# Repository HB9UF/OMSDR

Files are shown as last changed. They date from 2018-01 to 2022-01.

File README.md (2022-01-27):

# OMSDR: An SMD soldering practice kit for hams

## Introduction

OMSDR is a simple HF SDR receiver frontend inspired by the [SoftRock Lite II](http://fivedash.com/index.php?main_page=product_info&products_id=5). It is designed as SMD soldering practice kit to demonstrate the power of SMD technology, meant as an entry point for amateur radio hobbyists who are afraid of SMD. To allow for an easy entrance, most components are fairly large -- much larger than what you usually use in SMD designs. Our position is that SMD soldering is not hard if you know the proper techniques, and that a kit such as this one makes it easy to acquire these techniques. Note that this is not a particular good radio, and if you are not in for the aforementioned SMD aspects, you are probably better off with a different kit. If one of the following is of interest to you, though, then this may be for you:

1. Easy to assemble SMD kit with large parts and large footprints designed for entry level SMD hand soldering.
2. This kit makes for a good learning experience if you are interested in the Tayloe mixer circuitry that is the basis for these types of SDR frontends. The relevant signals are easy to probe, allowing for a deeper understanding of the circuit.

The circuit stored in this repository is designed for the 40 meter amateur radio band, although it is relatively easy (and hopefully instructional) to alter the design for operation on another band. If you do so, we would very much like to hear from you.

## Schematic
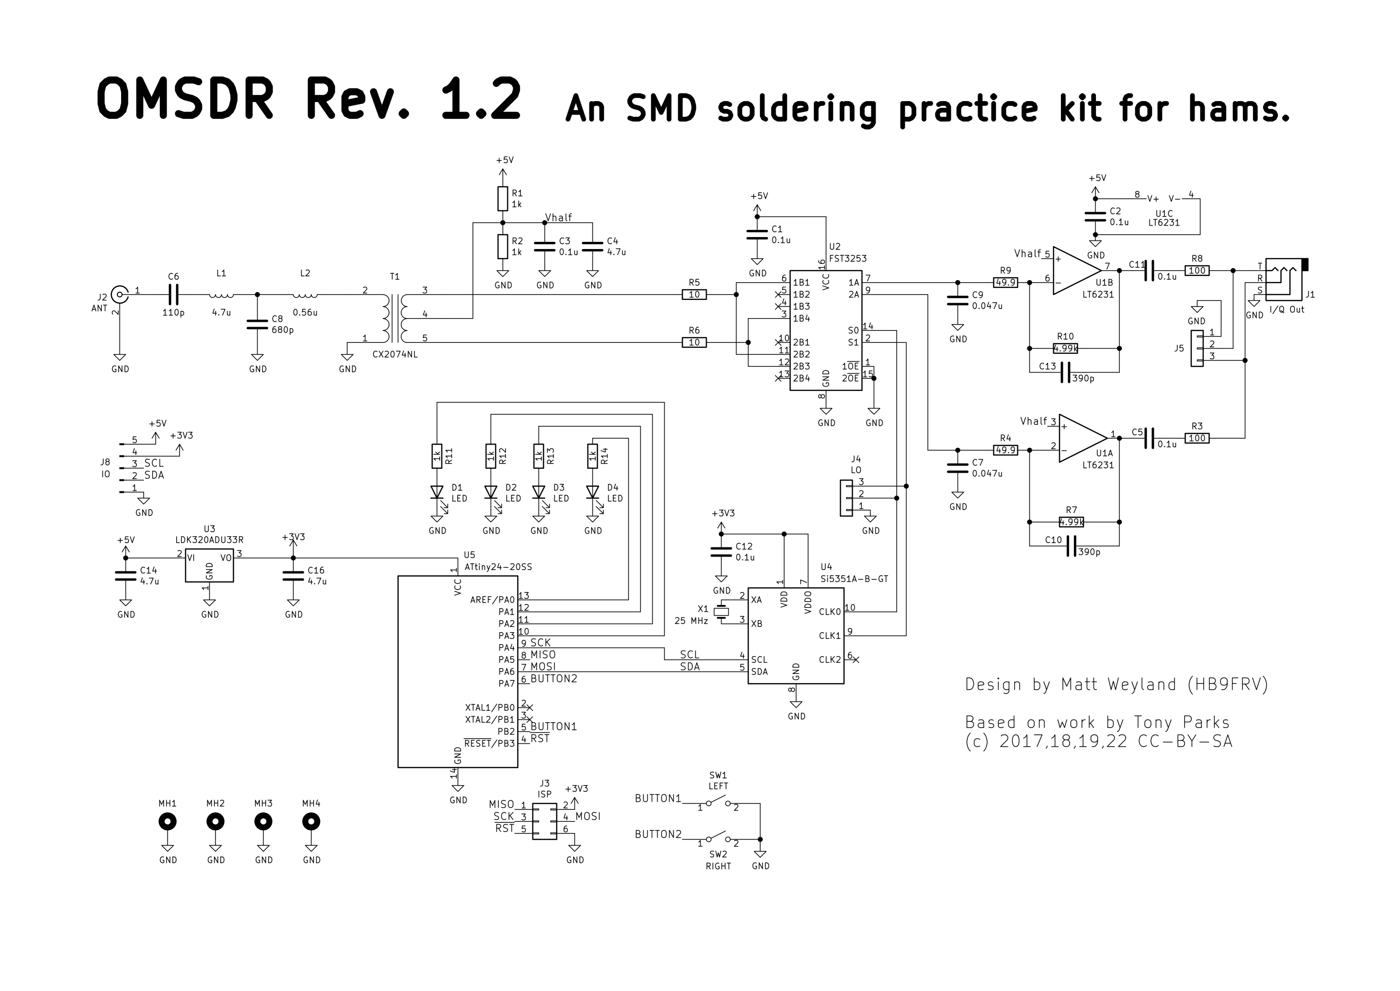
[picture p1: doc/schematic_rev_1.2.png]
Schematic rev 1.2


## Key differences to Soft Rock Lite II
This is not an exact copy of the design by Tony Parks. Instead, we opted for the following key differences:

- You don't have to wind any magnetic components. We use SMD inductors in the frontend filter (which we redesigned somewhat) and we use an SMD transformer (CX2074NL) for the balun.

- The original design employs a common-collector Colpitts oscillator to generate the reference for the local oscillator. We replaced that with a Silabs si5351 clock generator for versatility.

- The reference from the aforementioned Colpitts oscillation is fed into a dual D-Flip-Flop to generate a quadrature clock in the original design, yielding two square waves at a quarter of the reference frequency with a phase difference of 90°. We generate the quadrature clock directly with the si5351 clock generator.

- We use a microcontroller to program the clock generator. We chose an Attiny24 for this but this can be easily swapped out for something else. The clock generator is programmed via I2C and this bus is accessible through a pin header. Thus you could choose not to populate the microcontroller and use, e.g., a Raspberry Pi instead. Using a programmable clock generator allows us to change the center frequency of the SDR within the band, thus covering the whole 40 meter band. The original design has a fixed oscillator at approx. 7.056 MHz, thus even if you use a sampling rate of 96 kHz, it only covers the lower half of the band.

- a 3.5 mm audio jack can be plugged directly into the OMSDR board to connect to the sound card.

- Our design is fully open source.

## Bill of Materials

A BOM csv file is available [here](https://raw.githubusercontent.com/HB9UF/OMSDR/master/doc/BOM_rev1.2.csv) -- note that there is an aggregated table at the bottom. The `BOM` column follows the `bomtool` format, which is a retired tool by Alexis Lockwood. Essentially, digikey order numbers are prefixed with `DIST DIGIKEY` and for passives, we specify parts requirements that used to be processed by `bomtool` to pick the cheapest available part from digikey. Let us know if you are looking for a BOM or have compiled one yourself -- we have to transition to a new BOM format and that would be a good motivation to do so. Please also note that we did not include the pin headers because we believe that most builders will have those in bulk, and also because it pays off to buy them in bulk. For assembly, we have an interactive BOM [here](https://htmlpreview.github.io/?https://github.com/HB9UF/OMSDR/master/doc/ibom_rev1.2.html).

## Firmware

Firmware is available in the `firmware` subdirectory. To compile, run `make` and then flash the microcontroller using your favorite method, for example:

```
avrdude -v -pt44 -cstk500v2 -Pusb -Uflash:w:40m.hex:i
```

On a Debian system or a distribution based on Debian, you will need the packages `make`, `gcc-avr`, `avr-libc`, `binutils-avr` and `avrdude`  for this to work.

On power-up, the firmware cycles through the LEDs and initialized the local oscillator at 7.020 MHz. With a sound card sampling at 48 kHz, you will have access to the spectrum between 6.996 MHz and 7.044 MHz, i.e., the low end of the 40 meter amateur radio band. In this mode, the leftmost LED will be on and the remaining LEDs will be off: `[x][ ][ ][ ]`. Pushing the bottom button moves the center frequency to 7.060 MHz, covering the spectrum from 7.036 MHz to 7.084 MHz. The corresponding LED indicator reads `[x][x][ ][ ]`. In this manner, you can tune through different portions of the band according to the following frequency plan (center frequency indicated in parentheses):

```
       [x][ ][ ][ ]       [x][x][ ][ ]        [ ][x][x][ ]        [ ][ ][x][x]       [ ][ ][ ][x]
6.996  --(7.020)--  7.044
7.000  --(7.020)--  7.040
                    7.036  --(7.060)--  7.084
                    7.040  --(7.060)--  7.080
                                        7.076  --(7.100)--  7.124
                                        7.080  --(7.100)--  7.120
                                                            7.116  --(7.140)-- 7.164
                                                            7.120  --(7.140)-- 7.160
                                                                               7.156  --(7.180)-- 7.204
                                                                               7.160  --(7.180)-- 7.200
```

## Software and License
This board files were designed with KiCad 6. They are licensed under the CC-BY-SA license. More information on this license can be found [here](https://creativecommons.org/licenses/by-sa/4.0/). The software is licensed under the [GNU GENERAL PUBLIC LICENSE Version 3](https://www.gnu.org/licenses/gpl-3.0.en.html)

## References

The paper "Ultra Low Noise, High Performance, Zero IF Quadrature Product Detector and Preamplifier" by Dan Tayloe is a nice introduction to the principles of Tayloe quadrature product detectors. We are not sure where it was published originally, but it is available [here](http://www.norcalqrp.org/files/Tayloe_mixer_x3a.pdf). For a more intricate introduction, including software aspects, we refer to the article series "A Software-Defined Radio for the Masses" by Gerald Youngblood, published in the QEX journal in 2002 and 2003: [Part 1](https://www.arrl.org/files/file/Technology/tis/info/pdf/020708qex013.pdf), [Part 2](https://www.arrl.org/files/file/Technology/tis/info/pdf/020910qex010.pdf), [Part 3](https://www.arrl.org/files/file/Technology/tis/info/pdf/021112qex027.pdf), [Part 4](https://www.arrl.org/files/file/Technology/tis/info/pdf/030304qex020.pdf).

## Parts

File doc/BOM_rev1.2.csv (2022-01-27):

Individual Components:
Item | Qty | Reference(s) | Value | LibPart | Footprint | Datasheet | BOM
 |  | C1 | 0.1u | Device:C | Capacitor_SMD:C_1206_3216Metric_Pad1.33x1.80mm_HandSolder | ~ | CAP MLCC 0.1u ±10% ≥X7R [1206]
 |  | C2 | 0.1u | Device:C | Capacitor_SMD:C_1206_3216Metric_Pad1.33x1.80mm_HandSolder | ~ | CAP MLCC 0.1u ±10% ≥X7R [1206]
 |  | C3 | 0.1u | Device:C | Capacitor_SMD:C_1206_3216Metric_Pad1.33x1.80mm_HandSolder | ~ | CAP MLCC 0.1u ±10% ≥X7R [1206]
 |  | C4 | 4.7u | Device:C | Capacitor_SMD:C_1206_3216Metric_Pad1.33x1.80mm_HandSolder | ~ | CAP MLCC 4.7u ±20% 10V [1206]
 |  | C5 | 0.1u | Device:C | Capacitor_SMD:C_1206_3216Metric_Pad1.33x1.80mm_HandSolder | ~ | CAP MLCC 0.1u ±10% ≥X7R [1206]
 |  | C6 | 110p | Device:C | Capacitor_SMD:C_1206_3216Metric_Pad1.33x1.80mm_HandSolder | ~ | CAP MLCC 110p ±5% NP0 [1206]
 |  | C7 | 0.047u | Device:C | Capacitor_SMD:C_1206_3216Metric_Pad1.33x1.80mm_HandSolder | ~ | CAP MLCC 0.047u ±10% ≥X5R [1206]
 |  | C8 | 680p | Device:C | Capacitor_SMD:C_1206_3216Metric_Pad1.33x1.80mm_HandSolder | ~ | CAP MLCC 680p ±5% NP0 [1206]
 |  | C9 | 0.047u | Device:C | Capacitor_SMD:C_1206_3216Metric_Pad1.33x1.80mm_HandSolder | ~ | CAP MLCC 0.047u ±10% ≥X5R [1206]
 |  | C10 | 390p | Device:C | Capacitor_SMD:C_1206_3216Metric_Pad1.33x1.80mm_HandSolder | ~ | CAP MLCC 390p ±5% NP0 [1206]
 |  | C11 | 0.1u | Device:C | Capacitor_SMD:C_1206_3216Metric_Pad1.33x1.80mm_HandSolder | ~ | CAP MLCC 0.1u ±10% ≥X7R [1206]
 |  | C12 | 0.1u | Device:C | Capacitor_SMD:C_1206_3216Metric_Pad1.33x1.80mm_HandSolder | ~ | CAP MLCC 0.1u ±10% ≥X7R [1206]
 |  | C13 | 390p | Device:C | Capacitor_SMD:C_1206_3216Metric_Pad1.33x1.80mm_HandSolder | ~ | CAP MLCC 390p ±5% NP0 [1206]
 |  | C14 | 4.7u | Device:C | Capacitor_SMD:C_1206_3216Metric_Pad1.33x1.80mm_HandSolder | ~ | CAP MLCC 4.7u ±20% 10V [1206]
 |  | C16 | 4.7u | Device:C | Capacitor_SMD:C_1206_3216Metric_Pad1.33x1.80mm_HandSolder | ~ | CAP MLCC 4.7u ±20% 10V [1206]
 |  | D1 | LED | Device:LED | LED_SMD:LED_0805_2012Metric_Pad1.15x1.40mm_HandSolder | ~ | DIST DIGIKEY 732-4984-1-ND
 |  | D2 | LED | Device:LED | LED_SMD:LED_0805_2012Metric_Pad1.15x1.40mm_HandSolder | ~ | DIST DIGIKEY 732-4984-1-ND
 |  | D3 | LED | Device:LED | LED_SMD:LED_0805_2012Metric_Pad1.15x1.40mm_HandSolder | ~ | DIST DIGIKEY 732-4984-1-ND
 |  | D4 | LED | Device:LED | LED_SMD:LED_0805_2012Metric_Pad1.15x1.40mm_HandSolder | ~ | DIST DIGIKEY 732-4984-1-ND
 |  | J1 | I/Q Out | Connector:AudioJack3 | Connector_Audio:Jack_3.5mm_CUI_SJ-3523-SMT_Horizontal | ~ | DIST DIGIKEY CP-3523SJCT-ND
 |  | J2 | ANT | Connector:Conn_Coaxial | Connector_Coaxial:SMA_Samtec_SMA-J-P-X-ST-EM1_EdgeMount | ~ | DIST DIGIKEY CON-SMA-EDGE-S-ND
 |  | J3 | ISP | Connector_Generic:Conn_02x03_Odd_Even | Connector_PinHeader_2.54mm:PinHeader_2x03_P2.54mm_Vertical | ~ | DIST DIGIKEY 609-2846-ND
 |  | J4 | LO | Connector_Generic:Conn_01x03 | Connector_PinHeader_2.54mm:PinHeader_1x03_P2.54mm_Vertical | ~
 |  | J5 | I/Q Out | Connector_Generic:Conn_01x03 | Connector_PinHeader_2.54mm:PinHeader_1x03_P2.54mm_Vertical | ~
 |  | J8 | IO | Connector:Conn_01x05_Male | Connector_PinHeader_2.54mm:PinHeader_1x05_P2.54mm_Horizontal | ~
 |  | L1 | 4.7u | Device:L | Inductor_SMD:L_1206_3216Metric_Pad1.42x1.75mm_HandSolder | ~ | DIST DIGIKEY 587-2034-1-ND
 |  | L2 | 0.56u | Device:L | Inductor_SMD:L_0805_2012Metric_Pad1.15x1.40mm_HandSolder | ~ | DIST DIGIKEY LBM2016TR56J
 |  | MH1 |  | Mechanical:MountingHole_Pad | MountingHole:MountingHole_3.2mm_M3_Pad_Via | ~
 |  | MH2 |  | Mechanical:MountingHole_Pad | MountingHole:MountingHole_3.2mm_M3_Pad_Via | ~
 |  | MH3 |  | Mechanical:MountingHole_Pad | MountingHole:MountingHole_3.2mm_M3_Pad_Via | ~
 |  | MH4 |  | Mechanical:MountingHole_Pad | MountingHole:MountingHole_3.2mm_M3_Pad_Via | ~
 |  | R1 | 1k | Device:R | Resistor_SMD:R_1206_3216Metric_Pad1.30x1.75mm_HandSolder | ~ | RES SMD 1k 1% [1206]
 |  | R2 | 1k | Device:R | Resistor_SMD:R_1206_3216Metric_Pad1.30x1.75mm_HandSolder | ~ | RES SMD 1k 1% [1206]
 |  | R3 | 100 | Device:R | Resistor_SMD:R_1206_3216Metric_Pad1.30x1.75mm_HandSolder | ~ | RES SMD 100 1% [1206]
 |  | R4 | 49.9 | Device:R | Resistor_SMD:R_1206_3216Metric_Pad1.30x1.75mm_HandSolder | ~ | RES SMD 49.9 1% [1206]
 |  | R5 | 10 | Device:R | Resistor_SMD:R_1206_3216Metric_Pad1.30x1.75mm_HandSolder | ~ | RES SMD 10 1% [1206]
 |  | R6 | 10 | Device:R | Resistor_SMD:R_1206_3216Metric_Pad1.30x1.75mm_HandSolder | ~ | RES SMD 10 1% [1206]
 |  | R7 | 4.99k | Device:R | Resistor_SMD:R_1206_3216Metric_Pad1.30x1.75mm_HandSolder | ~ | RES SMD 4.99k 1% [1206]
 |  | R8 | 100 | Device:R | Resistor_SMD:R_1206_3216Metric_Pad1.30x1.75mm_HandSolder | ~ | RES SMD 100 1% [1206]
 |  | R9 | 49.9 | Device:R | Resistor_SMD:R_1206_3216Metric_Pad1.30x1.75mm_HandSolder | ~ | RES SMD 49.9 1% [1206]
 |  | R10 | 4.99k | Device:R | Resistor_SMD:R_1206_3216Metric_Pad1.30x1.75mm_HandSolder | ~ | RES SMD 4.99k 1% [1206]
 |  | R11 | 1k | Device:R | Resistor_SMD:R_1206_3216Metric_Pad1.30x1.75mm_HandSolder | ~ | RES SMD 1k 1% [0805]
 |  | R12 | 1k | Device:R | Resistor_SMD:R_1206_3216Metric_Pad1.30x1.75mm_HandSolder | ~ | RES SMD 1k 1% [0805]
 |  | R13 | 1k | Device:R | Resistor_SMD:R_1206_3216Metric_Pad1.30x1.75mm_HandSolder | ~ | RES SMD 1k 1% [0805]
 |  | R14 | 1k | Device:R | Resistor_SMD:R_1206_3216Metric_Pad1.30x1.75mm_HandSolder | ~ | RES SMD 1k 1% [0805]
 |  | SW1 | LEFT | Switch:SW_SPST | Button_Switch_SMD:SW_SPST_TL3342 | ~ | DIST DIGIKEY EG2531CT-ND
 |  | SW2 | RIGHT | Switch:SW_SPST | Button_Switch_SMD:SW_SPST_TL3342 | ~ | DIST DIGIKEY EG2531CT-ND
 |  | T1 | CX2074NL | Device:Transformer_1P_SS | local:CX2074 | ~ | DIST DIGIKEY 553-1655-ND
 |  | U1 | LT6231 | Amplifier_Operational:LT6234 | Package_SO:SO-8_3.9x4.9mm_P1.27mm | https://www.analog.com/media/en/technical-documentation/data-sheets/623345fc.pdf | DIST DIGIKEY LT6231CS8#PBF-ND
 |  | U2 | FST3253 | Analog_Switch:SN74CBT3253 | Package_SO:SOIC-16_3.9x9.9mm_P1.27mm | https://www.fairchildsemi.com/datasheets/FS/FST3253.pdf | DIST DIGIKEY 296-19206-1-ND
 |  | U3 | LDK320ADU33R | Regulator_Linear:MCP1703A-3302_SOT89 | Package_TO_SOT_SMD:SOT-89-3_Handsoldering | http://ww1.microchip.com/downloads/en/DeviceDoc/20005122B.pdf | DIST DIGIKEY 497-17585-1-ND
 |  | U4 | Si5351A-B-GT | Oscillator:Si5351A-B-GT | Package_SO:MSOP-10_3x3mm_P0.5mm | https://www.silabs.com/documents/public/data-sheets/Si5351-B.pdf | DIST DIGIKEY 336-3908-1-ND
 |  | U5 | ATtiny24-20SS | MCU_Microchip_ATtiny:ATtiny24-20SS | Package_SO:SOIC-14_3.9x8.7mm_P1.27mm | http://ww1.microchip.com/downloads/en/DeviceDoc/doc8006.pdf | DIST DIGIKEY ATTINY24A-SSU-ND
 |  | X1 | 25 MHz | Device:Crystal_Small | Crystal:Crystal_SMD_HC49-SD | ~ | DIST DIGIKEY 535-10235-1-ND
Collated Components:
Item | Qty | Reference(s) | Value | LibPart | Footprint | Datasheet | BOM
1 | 6 | C1, C2, C3, C5, C11, C12 | 0.1u | Device:C | Capacitor_SMD:C_1206_3216Metric_Pad1.33x1.80mm_HandSolder | ~ | CAP MLCC 0.1u ±10% ≥X7R [1206]
2 | 3 | C4, C14, C16 | 4.7u | Device:C | Capacitor_SMD:C_1206_3216Metric_Pad1.33x1.80mm_HandSolder | ~ | CAP MLCC 4.7u ±20% 10V [1206]
3 | 1 | C6 | 110p | Device:C | Capacitor_SMD:C_1206_3216Metric_Pad1.33x1.80mm_HandSolder | ~ | CAP MLCC 110p ±5% NP0 [1206]
4 | 2 | C7, C9 | 0.047u | Device:C | Capacitor_SMD:C_1206_3216Metric_Pad1.33x1.80mm_HandSolder | ~ | CAP MLCC 0.047u ±10% ≥X5R [1206]
5 | 1 | C8 | 680p | Device:C | Capacitor_SMD:C_1206_3216Metric_Pad1.33x1.80mm_HandSolder | ~ | CAP MLCC 680p ±5% NP0 [1206]
6 | 2 | C10, C13 | 390p | Device:C | Capacitor_SMD:C_1206_3216Metric_Pad1.33x1.80mm_HandSolder | ~ | CAP MLCC 390p ±5% NP0 [1206]
7 | 4 | D1, D2, D3, D4 | LED | Device:LED | LED_SMD:LED_0805_2012Metric_Pad1.15x1.40mm_HandSolder | ~ | DIST DIGIKEY 732-4984-1-ND
8 | 1 | J1 | I/Q Out | Connector:AudioJack3 | Connector_Audio:Jack_3.5mm_CUI_SJ-3523-SMT_Horizontal | ~ | DIST DIGIKEY CP-3523SJCT-ND
9 | 1 | J2 | ANT | Connector:Conn_Coaxial | Connector_Coaxial:SMA_Samtec_SMA-J-P-X-ST-EM1_EdgeMount | ~ | DIST DIGIKEY CON-SMA-EDGE-S-ND
10 | 1 | J3 | ISP | Connector_Generic:Conn_02x03_Odd_Even | Connector_PinHeader_2.54mm:PinHeader_2x03_P2.54mm_Vertical | ~ | DIST DIGIKEY 609-2846-ND
11 | 1 | J4 | LO | Connector_Generic:Conn_01x03 | Connector_PinHeader_2.54mm:PinHeader_1x03_P2.54mm_Vertical | ~
12 | 1 | J5 | I/Q Out | Connector_Generic:Conn_01x03 | Connector_PinHeader_2.54mm:PinHeader_1x03_P2.54mm_Vertical | ~
13 | 1 | J8 | IO | Connector:Conn_01x05_Male | Connector_PinHeader_2.54mm:PinHeader_1x05_P2.54mm_Horizontal | ~
14 | 1 | L1 | 4.7u | Device:L | Inductor_SMD:L_1206_3216Metric_Pad1.42x1.75mm_HandSolder | ~ | DIST DIGIKEY 587-2034-1-ND
15 | 1 | L2 | 0.56u | Device:L | Inductor_SMD:L_0805_2012Metric_Pad1.15x1.40mm_HandSolder | ~ | DIST DIGIKEY LBM2016TR56J
16 | 4 | MH1, MH2, MH3, MH4 |  | Mechanical:MountingHole_Pad | MountingHole:MountingHole_3.2mm_M3_Pad_Via | ~
17 | 6 | R1, R2, R11, R12, R13, R14 | 1k | Device:R | Resistor_SMD:R_1206_3216Metric_Pad1.30x1.75mm_HandSolder | ~ | RES SMD 1k 1% [1206]
18 | 2 | R3, R8 | 100 | Device:R | Resistor_SMD:R_1206_3216Metric_Pad1.30x1.75mm_HandSolder | ~ | RES SMD 100 1% [1206]
19 | 2 | R4, R9 | 49.9 | Device:R | Resistor_SMD:R_1206_3216Metric_Pad1.30x1.75mm_HandSolder | ~ | RES SMD 49.9 1% [1206]
20 | 2 | R5, R6 | 10 | Device:R | Resistor_SMD:R_1206_3216Metric_Pad1.30x1.75mm_HandSolder | ~ | RES SMD 10 1% [1206]
21 | 2 | R7, R10 | 4.99k | Device:R | Resistor_SMD:R_1206_3216Metric_Pad1.30x1.75mm_HandSolder | ~ | RES SMD 4.99k 1% [1206]
22 | 1 | SW1 | LEFT | Switch:SW_SPST | Button_Switch_SMD:SW_SPST_TL3342 | ~ | DIST DIGIKEY EG2531CT-ND
23 | 1 | SW2 | RIGHT | Switch:SW_SPST | Button_Switch_SMD:SW_SPST_TL3342 | ~ | DIST DIGIKEY EG2531CT-ND
24 | 1 | T1 | CX2074NL | Device:Transformer_1P_SS | local:CX2074 | ~ | DIST DIGIKEY 553-1655-ND
25 | 1 | U1 | LT6231 | Amplifier_Operational:LT6234 | Package_SO:SO-8_3.9x4.9mm_P1.27mm | https://www.analog.com/media/en/technical-documentation/data-sheets/623345fc.pdf | DIST DIGIKEY LT6231CS8#PBF-ND
26 | 1 | U2 | FST3253 | Analog_Switch:SN74CBT3253 | Package_SO:SOIC-16_3.9x9.9mm_P1.27mm | https://www.fairchildsemi.com/datasheets/FS/FST3253.pdf | DIST DIGIKEY 296-19206-1-ND
27 | 1 | U3 | LDK320ADU33R | Regulator_Linear:MCP1703A-3302_SOT89 | Package_TO_SOT_SMD:SOT-89-3_Handsoldering | http://ww1.microchip.com/downloads/en/DeviceDoc/20005122B.pdf | DIST DIGIKEY 497-17585-1-ND
28 | 1 | U4 | Si5351A-B-GT | Oscillator:Si5351A-B-GT | Package_SO:MSOP-10_3x3mm_P0.5mm | https://www.silabs.com/documents/public/data-sheets/Si5351-B.pdf | DIST DIGIKEY 336-3908-1-ND
29 | 1 | U5 | ATtiny24-20SS | MCU_Microchip_ATtiny:ATtiny24-20SS | Package_SO:SOIC-14_3.9x8.7mm_P1.27mm | http://ww1.microchip.com/downloads/en/DeviceDoc/doc8006.pdf | DIST DIGIKEY ATTINY24A-SSU-ND
30 | 1 | X1 | 25 MHz | Device:Crystal_Small | Crystal:Crystal_SMD_HC49-SD | ~ | DIST DIGIKEY 535-10235-1-ND

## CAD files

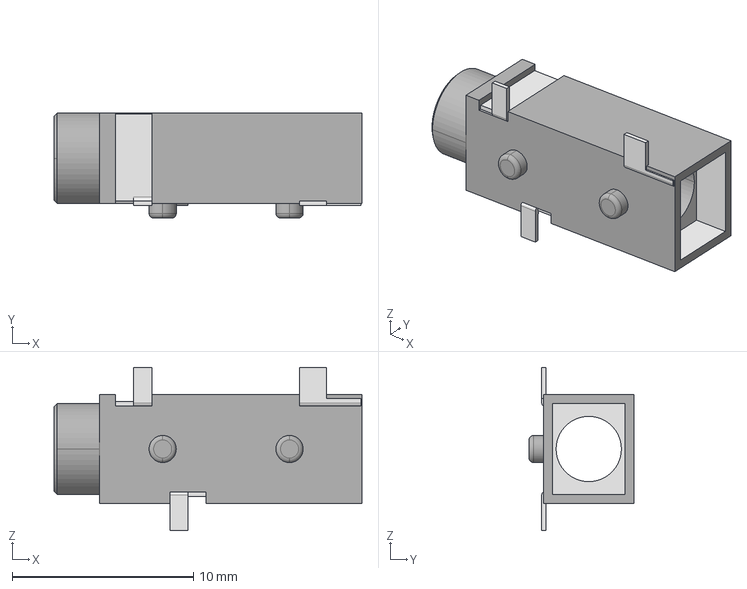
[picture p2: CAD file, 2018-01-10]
3d_models/sj-3523-smt.stp
17.0 x 5.80 x 9.00 mm

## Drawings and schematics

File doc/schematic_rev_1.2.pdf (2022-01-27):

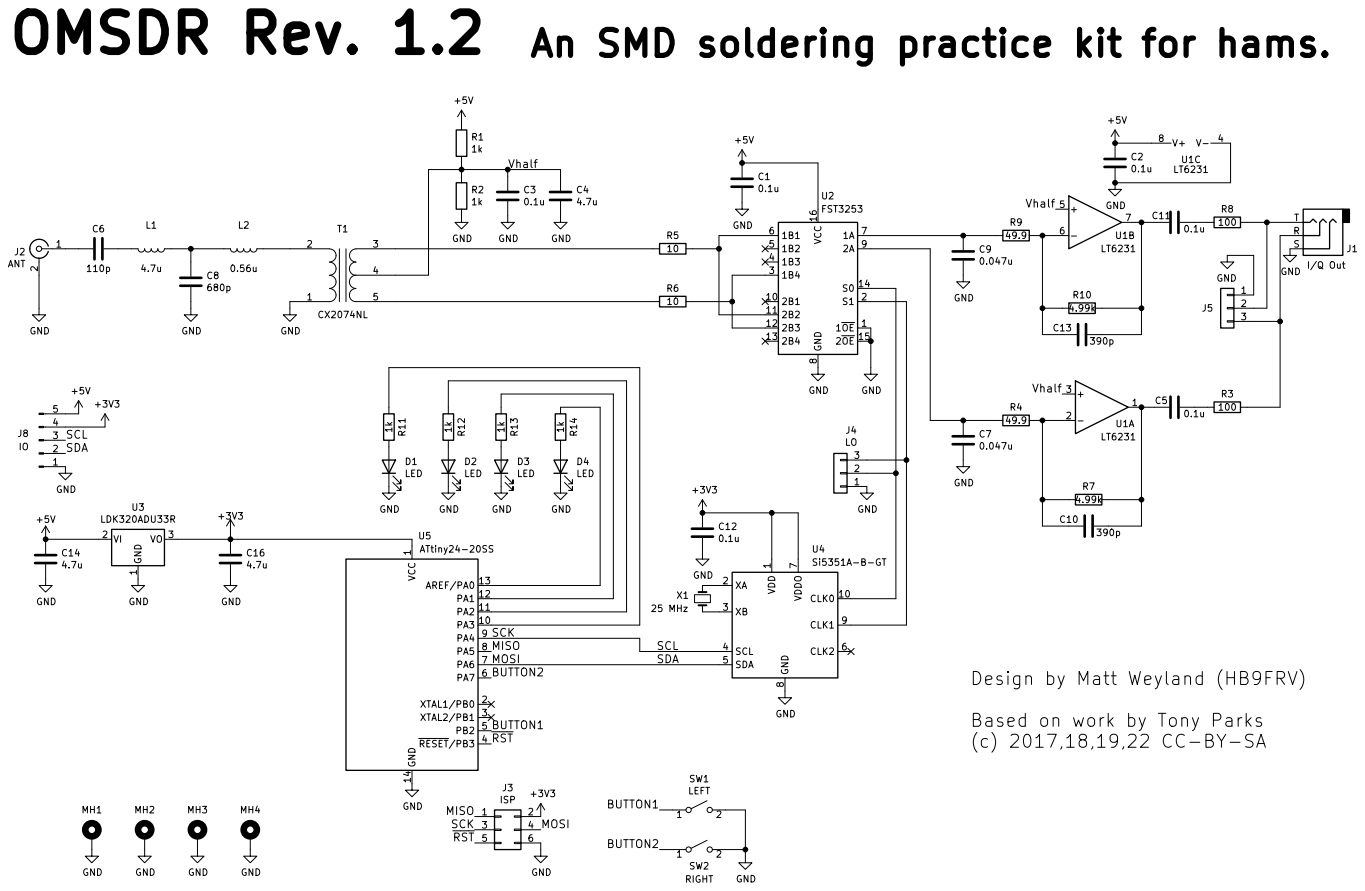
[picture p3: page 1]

1 CLK0 10 XA 2 XB 3 SCL 4 SDA 5 CLK2 6 VDDO

Design by Matt Weyland (HB9FRV)

Based on work by Tony Parks

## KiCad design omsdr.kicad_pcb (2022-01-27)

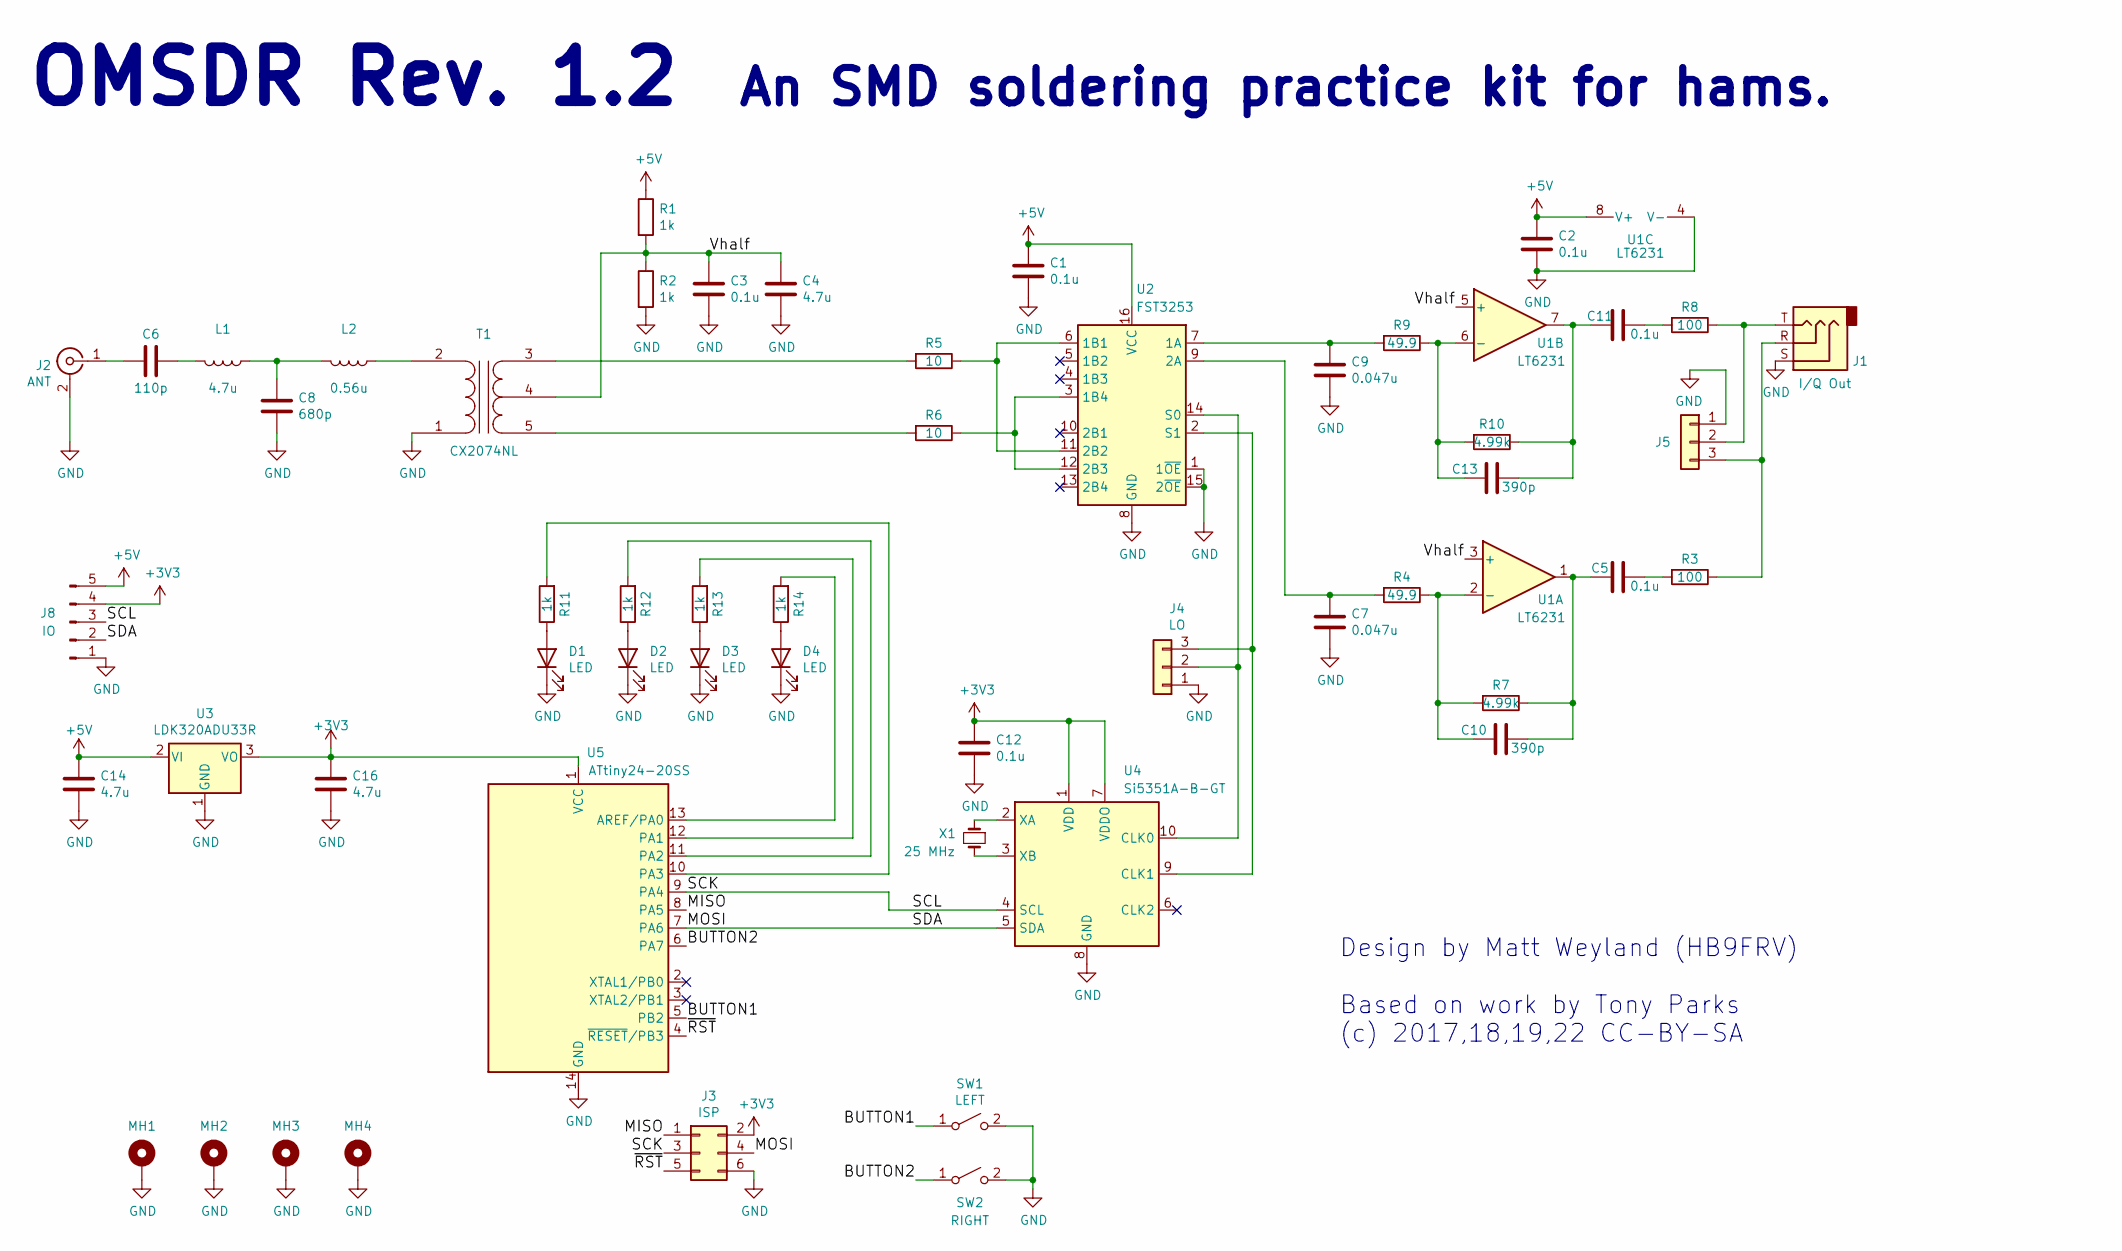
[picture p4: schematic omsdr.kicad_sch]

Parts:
C1, C2, C3, C5, C11, C12: 0.1u; C_1206_3216Metric_Pad1.33x1.80mm_HandSolder
C4, C14, C16: 4.7u; C_1206_3216Metric_Pad1.33x1.80mm_HandSolder
C6: 110p; C_1206_3216Metric_Pad1.33x1.80mm_HandSolder
C7, C9: 0.047u; C_1206_3216Metric_Pad1.33x1.80mm_HandSolder
C8: 680p; C_1206_3216Metric_Pad1.33x1.80mm_HandSolder
C10, C13: 390p; C_1206_3216Metric_Pad1.33x1.80mm_HandSolder
D1, D2, D3, D4: LED; LED_0805_2012Metric_Pad1.15x1.40mm_HandSolder
J1: I/Q Out; Jack_3.5mm_CUI_SJ-3523-SMT_Horizontal
J2: ANT; SMA_Samtec_SMA-J-P-X-ST-EM1_EdgeMount
J3: ISP; PinHeader_2x03_P2.54mm_Vertical
J4: LO; PinHeader_1x03_P2.54mm_Vertical
J5: I/Q Out; PinHeader_1x03_P2.54mm_Vertical
J8: IO; PinHeader_1x05_P2.54mm_Horizontal
L1: 4.7u; L_1206_3216Metric_Pad1.42x1.75mm_HandSolder
L2: 0.56u; L_0805_2012Metric_Pad1.15x1.40mm_HandSolder
MH1, MH2, MH3, MH4: MountingHole_3.2mm_M3_Pad_Via
R1, R2, R11, R12, R13, R14: 1k; R_1206_3216Metric_Pad1.30x1.75mm_HandSolder
R3, R8: 100; R_1206_3216Metric_Pad1.30x1.75mm_HandSolder
R4, R9: 49.9; R_1206_3216Metric_Pad1.30x1.75mm_HandSolder
R5, R6: 10; R_1206_3216Metric_Pad1.30x1.75mm_HandSolder
R7, R10: 4.99k; R_1206_3216Metric_Pad1.30x1.75mm_HandSolder
SW1: LEFT; SW_SPST_TL3342
SW2: RIGHT; SW_SPST_TL3342
T1: CX2074NL; CX2074
U1: LT6231; SO-8_3.9x4.9mm_P1.27mm
U2: FST3253; SOIC-16_3.9x9.9mm_P1.27mm
U3: LDK320ADU33R; SOT-89-3_Handsoldering
U4: Si5351A-B-GT; MSOP-10_3x3mm_P0.5mm
U5: ATtiny24-20SS; SOIC-14_3.9x8.7mm_P1.27mm
X1: 25 MHz; Crystal_SMD_HC49-SD

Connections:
+3V3: C12.1, C16.1, J3.2, J8.4, U3.3 (VO), U4.1 (VDD), U4.7 (VDDO), U5.1 (VCC)
+5V: C1.1, C2.1, C14.1, J8.5, R1.1, U1.8 (V+), U2.16 (VCC), U3.2 (VI)
/BUTTON1: SW1.1 (A), U5.5 (PB2)
/BUTTON2: SW2.1 (A), U5.6 (PA7)
/MISO: J3.1, U5.8 (PA5)
/MOSI: J3.4, J8.2, U4.5 (SDA), U5.7 (PA6)
/SCK: J3.3, J8.3, U4.4 (SCL), U5.9 (PA4)
/Vhalf: C3.1, C4.1, R1.2, R2.1, T1.4 (SC), U1.3 (+), U1.5 (+)
/~RST: J3.5, U5.4 (~RESET/PB3)
GND: C1.2, C2.2, C3.2, C4.2, C7.2, C8.2, C9.2, C12.2, C14.2, C16.2, D1.1 (K), D2.1 (K), D3.1 (K), D4.1 (K), J1.S, J2.2 (Ext), J3.6, J4.1, J5.1, J8.1, MH1.1, MH2.1, MH3.1, MH4.1, R2.2, SW1.2 (B), SW2.2 (B), T1.1 (AA), U1.4 (V-), U2.1 (1~OE), U2.8 (GND), U2.15 (2~OE), U3.1 (GND), U4.8 (GND), U5.14 (GND)
unnamed: C5.2, R3.2
unnamed: C6.1, L1.2
unnamed: C6.2, J2.1 (In)
unnamed: C7.1, R4.2, U2.9 (2A)
unnamed: C8.1, L1.1, L2.2
unnamed: C9.1, R9.2, U2.7 (1A)
unnamed: C10.1, R4.1, R7.2, U1.2 (-)
unnamed: C5.1, C10.2, R7.1, U1.1
unnamed: C11.1, C13.2, R10.1, U1.7
unnamed: C11.2, R8.2
unnamed: C13.1, R9.1, R10.2, U1.6 (-)
unnamed: D1.2 (A), R11.1
unnamed: D2.2 (A), R12.1
unnamed: D3.2 (A), R13.1
unnamed: D4.2 (A), R14.1
unnamed: J1.R, J5.3, R3.1
unnamed: J1.T, J5.2, R8.1
unnamed: J4.2, U2.14 (S0), U4.10 (CLK0)
unnamed: J4.3, U2.2 (S1), U4.9 (CLK1)
unnamed: L2.1, T1.2 (AB)
unnamed: R5.1, U2.6 (1B1), U2.11 (2B2)
unnamed: R5.2, T1.3 (SA)
unnamed: R6.1, U2.3 (1B4), U2.12 (2B3)
unnamed: R6.2, T1.5 (SB)
unnamed: R11.2, U5.10 (PA3)
unnamed: R12.2, U5.11 (PA2)
unnamed: R13.2, U5.12 (PA1)
unnamed: R14.2, U5.13 (AREF/PA0)
unnamed: U4.2 (XA), X1.1
unnamed: U4.3 (XB), X1.2

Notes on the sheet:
An SMD soldering practice kit for hams.
Design by Matt Weyland (HB9FRV) Based on work by Tony Parks (c) 2017,18,19,22 CC-BY-SA
OMSDR Rev. 1.2

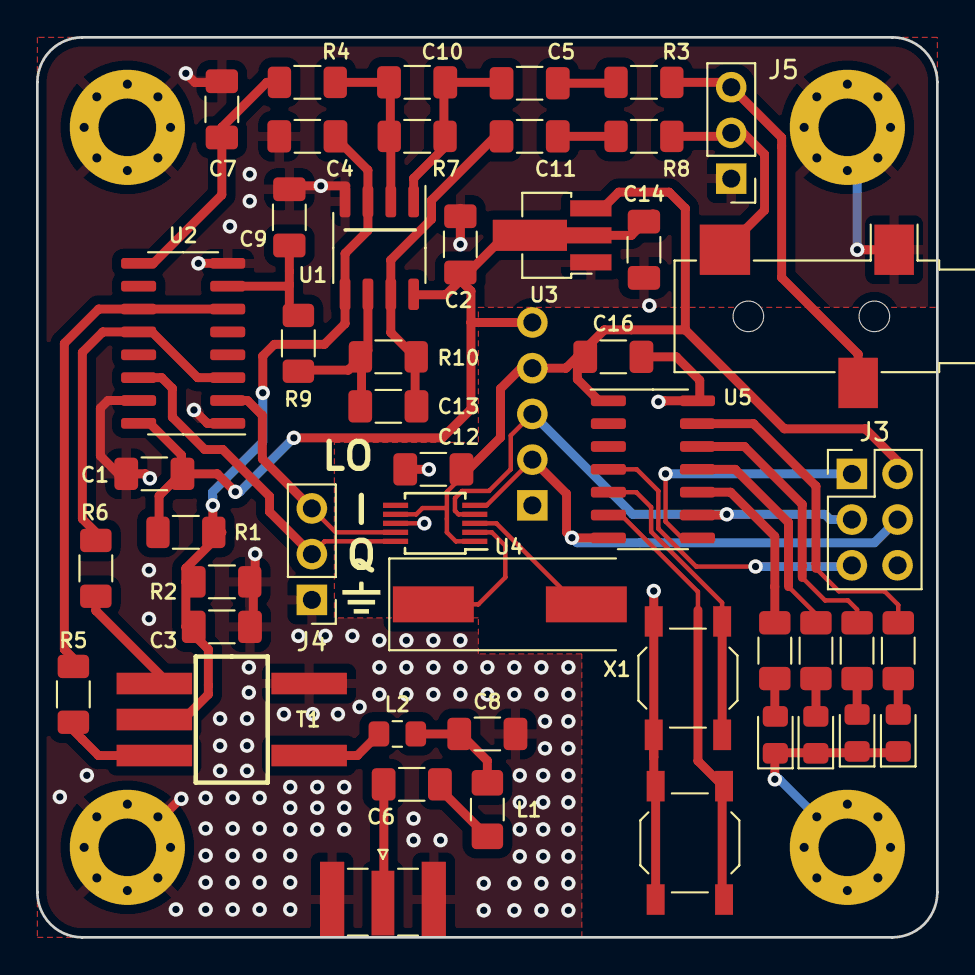
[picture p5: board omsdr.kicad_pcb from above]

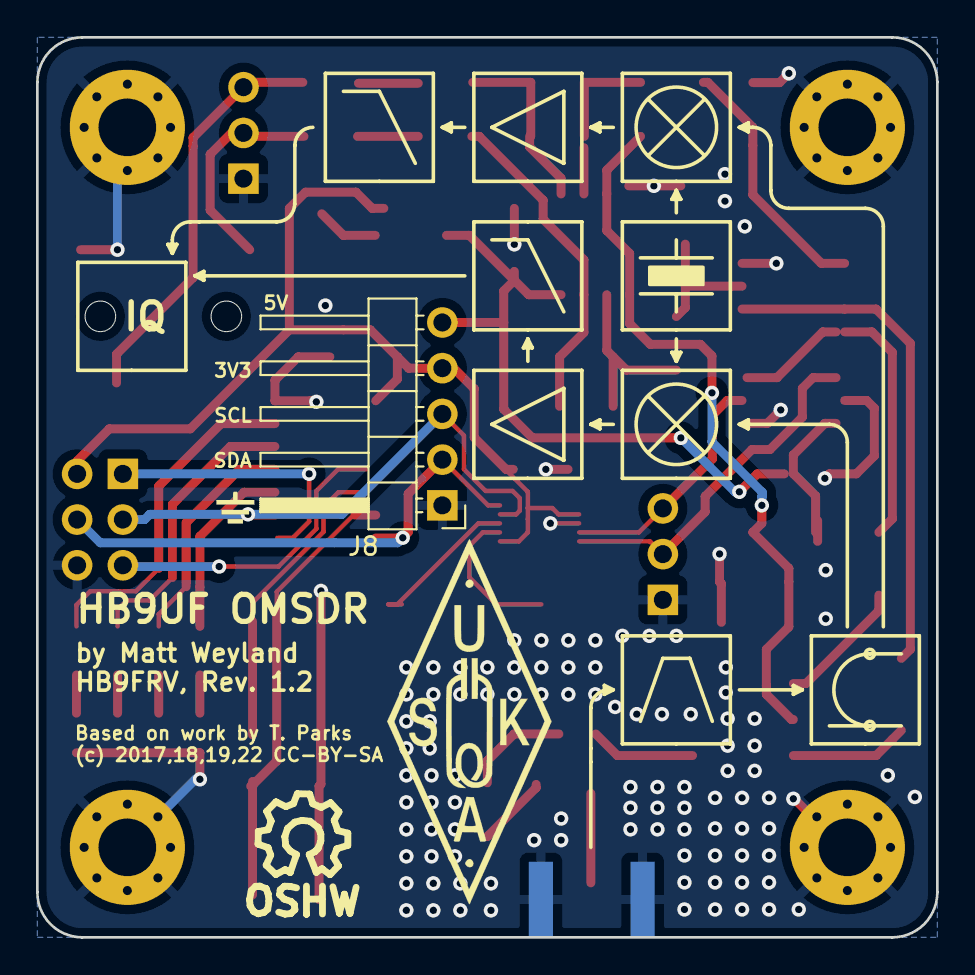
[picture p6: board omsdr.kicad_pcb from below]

Board: 2 copper layers, 50.0 x 50.0 mm, 57 parts (3 on the bottom side), 40 nets.

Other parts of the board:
SYM: Symbol_OSHW-Logo_SilkScreen_07Jul2012; Symbol_OSHW-Logo_SilkScreen
VAL: GND
VAL#2: GND

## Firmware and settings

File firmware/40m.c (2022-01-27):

#include <stdbool.h>
#include <avr/io.h>
#include <util/delay.h>

#include "i2c.h"

enum freq_t { FREQ_OFF, FREQ_7020, FREQ_7060, FREQ_7100, FREQ_7140, FREQ_7180} freq = FREQ_7020;

void io_init(void)
{
    // Our 4 LEDs
    DDRA = 0b00001111;
    // Pull-ups for two push buttons
    PORTB = 0b00000100; // PB1
    PORTA = 0b10000000; // PB2
}

bool io_get_pb1(void)
{
    // true == pushed
    return ! (PINB & (1 << 2));
}

bool io_get_pb2(void)
{
    // true == pushed
    return ! (PINA & (1 << 7));
}


void si5351_40m(enum freq_t f)
{
    if(f == FREQ_OFF)
    {
        i2c_write(0b1100000, 0x3, 0xFF);
        return;
    }
    // This was generated with the silabs tool. It seems to work but was obviously not optimized...
    i2c_write(0b1100000, 0xB7, 0x92);
    i2c_write(0b1100000, 0x1A, 0x0);
    i2c_write(0b1100000, 0x1B, 0x1);
    i2c_write(0b1100000, 0x1C, 0x0);
    i2c_write(0b1100000, 0x1D, 0xA);
    i2c_write(0b1100000, 0x1E, 0x0);
    i2c_write(0b1100000, 0x1F, 0x0);
    i2c_write(0b1100000, 0x20, 0x0);
    i2c_write(0b1100000, 0x21, 0x0);
    i2c_write(0b1100000, 0x22, 0x0);
    i2c_write(0b1100000, 0x23, 0x1);
    i2c_write(0b1100000, 0x24, 0x0);
    i2c_write(0b1100000, 0x25, 0xA);
    i2c_write(0b1100000, 0x26, 0x0);
    i2c_write(0b1100000, 0x27, 0x0);
    i2c_write(0b1100000, 0x28, 0x0);
    i2c_write(0b1100000, 0x29, 0x0);

    i2c_write(0b1100000, 0x10, 0x80);
    i2c_write(0b1100000, 0x11, 0x80);
    i2c_write(0b1100000, 0x12, 0x80);
    i2c_write(0b1100000, 0x13, 0x80);
    i2c_write(0b1100000, 0x14, 0x80);
    i2c_write(0b1100000, 0x15, 0x80);
    i2c_write(0b1100000, 0x16, 0x80);
    i2c_write(0b1100000, 0x17, 0x80);
    i2c_write(0b1100000, 0x10, 0xC);
    i2c_write(0b1100000, 0x11, 0xC);
    i2c_write(0b1100000, 0x12, 0xC);
    i2c_write(0b1100000, 0x13, 0xC);
    i2c_write(0b1100000, 0x14, 0xC);
    i2c_write(0b1100000, 0x15, 0xC);
    i2c_write(0b1100000, 0x16, 0xC);
    i2c_write(0b1100000, 0x17, 0xC);
    i2c_write(0b1100000, 0x1A, 0x0);
    i2c_write(0b1100000, 0x1B, 0x1);
    i2c_write(0b1100000, 0x1C, 0x0);
    i2c_write(0b1100000, 0x1D, 0xE);
    i2c_write(0b1100000, 0x1E, 0x0);
    i2c_write(0b1100000, 0x1F, 0x0);
    i2c_write(0b1100000, 0x20, 0x0);
    i2c_write(0b1100000, 0x21, 0x0);
    i2c_write(0b1100000, 0x22, 0x0);
    i2c_write(0b1100000, 0x23, 0x1);
    i2c_write(0b1100000, 0x24, 0x0);
    i2c_write(0b1100000, 0x25, 0xE);
    i2c_write(0b1100000, 0x26, 0x0);
    i2c_write(0b1100000, 0x27, 0x0);
    i2c_write(0b1100000, 0x28, 0x0);
    i2c_write(0b1100000, 0x29, 0x0);

    i2c_write(0b1100000, 0x10, 0xC);
    i2c_write(0b1100000, 0x11, 0xC);
    i2c_write(0b1100000, 0x12, 0xC);
    i2c_write(0b1100000, 0x13, 0xC);
    i2c_write(0b1100000, 0x14, 0xC);
    i2c_write(0b1100000, 0x15, 0xC);
    i2c_write(0b1100000, 0x16, 0x2C);
    i2c_write(0b1100000, 0x17, 0x2C);
    i2c_write(0b1100000, 0xA2, 0x0);
    i2c_write(0b1100000, 0xA3, 0x0);
    i2c_write(0b1100000, 0xA4, 0x0);
    i2c_write(0b1100000, 0xB1, 0x20);
    i2c_write(0b1100000, 0xB1, 0x80);
    i2c_write(0b1100000, 0x3, 0xFF);
    i2c_write(0b1100000, 0x1A, 0x42);
    i2c_write(0b1100000, 0x1B, 0x40);
    i2c_write(0b1100000, 0x1C, 0x0);
    i2c_write(0b1100000, 0x1D, 0xC);
    i2c_write(0b1100000, 0x1E, 0x19);
    i2c_write(0b1100000, 0x1F, 0xF9);
    i2c_write(0b1100000, 0x20, 0x27);
    i2c_write(0b1100000, 0x21, 0xC0);
    i2c_write(0b1100000, 0x3, 0xFE);
    i2c_write(0b1100000, 0x2A, 0x42);
    i2c_write(0b1100000, 0x2B, 0x40);
    i2c_write(0b1100000, 0x2C, 0x0);
    switch(freq)
    {
        case FREQ_7020:
            i2c_write(0b1100000, 0x2D, 0x30);
            i2c_write(0b1100000, 0x2E, 0x36);
            i2c_write(0b1100000, 0x2F, 0xFA);
            i2c_write(0b1100000, 0x30, 0xB1);
            i2c_write(0b1100000, 0x31, 0x80);
            break;
        case FREQ_7060:
            i2c_write(0b1100000, 0x2D, 0x2F);
            i2c_write(0b1100000, 0x2E, 0xED);
            i2c_write(0b1100000, 0x2F, 0xFD);
            i2c_write(0b1100000, 0x30, 0x44);
            i2c_write(0b1100000, 0x31, 0xC0);
            break;
        case FREQ_7100:
            i2c_write(0b1100000, 0x2D, 0x2F);
            i2c_write(0b1100000, 0x2E, 0xA5);
            i2c_write(0b1100000, 0x2F, 0xFD);
            i2c_write(0b1100000, 0x30, 0x1B);
            i2c_write(0b1100000, 0x31, 0xC0);
            break;
        case FREQ_7140:
            i2c_write(0b1100000, 0x2D, 0x2F);
            i2c_write(0b1100000, 0x2E, 0x5E);
            i2c_write(0b1100000, 0x2F, 0xFA);
            i2c_write(0b1100000, 0x30, 0x00);
            i2c_write(0b1100000, 0x31, 0x00);
            break;
        case FREQ_7180:
            i2c_write(0b1100000, 0x2D, 0x2F);
            i2c_write(0b1100000, 0x2E, 0x18);
            i2c_write(0b1100000, 0x2F, 0xF3);
            i2c_write(0b1100000, 0x30, 0xBD);
            i2c_write(0b1100000, 0x31, 0x80);
            break;
    }
    i2c_write(0b1100000, 0x10, 0xC);
    i2c_write(0b1100000, 0x2C, 0x0);
    i2c_write(0b1100000, 0x1A, 0x42);
    i2c_write(0b1100000, 0x1B, 0x40);
    i2c_write(0b1100000, 0x1C, 0x0);
    i2c_write(0b1100000, 0x1D, 0xC);
    i2c_write(0b1100000, 0x1E, 0x19);
    i2c_write(0b1100000, 0x1F, 0xF9);
    i2c_write(0b1100000, 0x20, 0x27);
    i2c_write(0b1100000, 0x21, 0xC0);
    i2c_write(0b1100000, 0x3, 0xFC);
    i2c_write(0b1100000, 0x32, 0x42);
    i2c_write(0b1100000, 0x33, 0x40);
    i2c_write(0b1100000, 0x34, 0x0);
    switch(freq)
    {
        case FREQ_7020:
            i2c_write(0b1100000, 0x35, 0x30);
            i2c_write(0b1100000, 0x36, 0x36);
            i2c_write(0b1100000, 0x37, 0xFA);
            i2c_write(0b1100000, 0x38, 0xB1);
            i2c_write(0b1100000, 0x39, 0x80);
            break;
        case FREQ_7060:
            i2c_write(0b1100000, 0x35, 0x2F);
            i2c_write(0b1100000, 0x36, 0xED);
            i2c_write(0b1100000, 0x37, 0xFD);
            i2c_write(0b1100000, 0x38, 0x44);
            i2c_write(0b1100000, 0x39, 0xC0);
            break;
        case FREQ_7100:
            i2c_write(0b1100000, 0x35, 0x2F);
            i2c_write(0b1100000, 0x36, 0xA5);
            i2c_write(0b1100000, 0x37, 0xFD);
            i2c_write(0b1100000, 0x38, 0x1B);
            i2c_write(0b1100000, 0x39, 0xC0);
            break;
        case FREQ_7140:
            i2c_write(0b1100000, 0x35, 0x2F);
            i2c_write(0b1100000, 0x36, 0x5E);
            i2c_write(0b1100000, 0x37, 0xFA);
            i2c_write(0b1100000, 0x38, 0x00);
            i2c_write(0b1100000, 0x39, 0x00);
            break;
        case FREQ_7180:
            i2c_write(0b1100000, 0x35, 0x2F);
            i2c_write(0b1100000, 0x36, 0x18);
            i2c_write(0b1100000, 0x37, 0xF3);
            i2c_write(0b1100000, 0x38, 0xBD);
            i2c_write(0b1100000, 0x39, 0x80);
            break;
    }
    i2c_write(0b1100000, 0x11, 0xC);
    i2c_write(0b1100000, 0x34, 0x0);
    i2c_write(0b1100000, 0xA5, 0x0);
    i2c_write(0b1100000, 0xA6, 0x64);
    i2c_write(0b1100000, 0xB1, 0x20);
}

void si5351_init(void)
{
}

void io_led(uint8_t i)
{
    if(i > 3) return;
    // Turn off all LEDs
    PORTA = PORTA & 0b11110000;
    // Turn on specific LED
    PORTA |= (1 << i);
}

void io_led_pattern(enum freq_t f)
{
    // Turn off all LEDs
    PORTA = PORTA & 0b11110000;
    switch(f)
    {
        case FREQ_7180:
            PORTA |= 0b1;
            break;
        case FREQ_7140:
            PORTA |= 0b11;
            break;
        case FREQ_7100:
            PORTA |= 0b110;
            break;
        case FREQ_7060:
            PORTA |= 0b1100;
            break;
        case FREQ_7020:
            PORTA |= 0b1000;
            break;
        case FREQ_OFF:
            break;
    }
}

void io_led_larsson(void)
{
    io_led_pattern(FREQ_7020);
    _delay_ms(100);
    io_led_pattern(FREQ_7060);
    _delay_ms(100);
    io_led_pattern(FREQ_7100);
    _delay_ms(100);
    io_led_pattern(FREQ_7140);
    _delay_ms(100);
    io_led_pattern(FREQ_7180);
    _delay_ms(100);
    io_led_pattern(FREQ_7140);
    _delay_ms(100);
    io_led_pattern(FREQ_7100);
    _delay_ms(100);
    io_led_pattern(FREQ_7060);
    _delay_ms(100);
    io_led_pattern(FREQ_7020);
    _delay_ms(100);
}


int main(void)
{
    io_init();
    i2c_init();
    si5351_init();

    io_led_larsson();
    io_led_pattern(freq);
    si5351_40m(freq);

    while(1)
    {
        if(freq < FREQ_7180 && io_get_pb1())
        {
            freq++;
            io_led_pattern(freq);
            si5351_40m(freq);
            //while(!io_get_pb1());
            _delay_ms(200);
        }
        if(freq > FREQ_OFF && io_get_pb2())
        {
            freq--;
            io_led_pattern(freq);
            si5351_40m(freq);
            //while(!io_get_pb2());
            _delay_ms(200);
        }
    }
}

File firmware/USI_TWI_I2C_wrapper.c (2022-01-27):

/* This is unplanned. The microcontroller we chose does have a hardware I2C
 * peripheral but there doesn't seem to be a way to use internal pull-ups in
 * TWI mode fore I2C (see table 14-1 on p. 124 of the datasheet). Hence, we
 * re-implement the I2C functions as wrapper around a bit-banged I2C
 * implementation.
 *
 * SCL is PA4, SDA is PA6
 */

#include <stdint.h>
#include <stdbool.h>

#include <avr/io.h>
#include <util/delay.h>

void i2c_scl_hi(void)
{
    DDRA  &= ~(1 << 4);
    PORTA |=  (1 << 4);
}

void i2c_scl_lo(void)
{
    DDRA  |=  (1 << 4);
    PORTA &= ~(1 << 4);
}

void i2c_sda_hi(void)
{
    DDRA  &= ~(1 << 6);
    PORTA |=  (1 << 6);
}

void i2c_sda_lo(void)
{
    DDRA  |=  (1 << 6);
    PORTA &= ~(1 << 6);
}

void i2c_delay(void)
{
    // FIXME: Calculate rate
    _delay_us(10);
}

void i2c_start(void)
{
    i2c_sda_hi();
    i2c_scl_hi();
    i2c_delay();
    i2c_sda_lo();
    i2c_delay();
    i2c_scl_lo();
    i2c_delay();
}

void i2c_stop(void)
{
    i2c_scl_lo();
    i2c_delay();
    i2c_sda_lo();
    i2c_delay();
    i2c_scl_hi();
    i2c_delay();
    i2c_sda_hi();
    i2c_delay();
}

void i2c_byte(uint8_t byte)
{
    for(uint8_t i=0; i<8; i++)
    {
        bool bit = byte & 0x80;
        bit ? i2c_sda_hi() : i2c_sda_lo();
        i2c_delay();
        i2c_scl_hi();
        i2c_delay();
        i2c_scl_lo();
        i2c_delay();
        byte <<= 1;
    }
    i2c_sda_hi();
    i2c_delay();
    i2c_scl_hi();
    i2c_delay(); // Here we can poll for the ACK
    i2c_scl_lo();
}

// addr is 7-bit device address
void i2c_write(uint8_t addr, uint8_t reg, uint8_t data)
{
    i2c_start();
    i2c_byte(addr << 1);
    i2c_byte(reg);
    i2c_byte(data);
    i2c_stop();

}

void i2c_init(void)
{
    i2c_sda_hi();
    i2c_scl_hi();
}

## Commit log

2018-01-10 Initial commit on the road to v1.1
    [omsdr.kicad_pcb, omsdr.sch]
2018-01-10 Initial commit of local 3d models
    [901-10003_REV-A.igs, TL3342FxxxQG.stp, sj-3523-smt.stp]
2018-01-10 Fix paths to local 3d models
    [omsdr.kicad_pcb]
2018-01-17 Replace 3.3 V regul L78L33ABUTR with LDK320ADU33R
    Almost same price, lower noise, better PSSR and slightly better
    pinout. Same SOT-89 package. Chances in schematic and PCB.
    [omsdr.kicad_pcb, omsdr.sch]
2018-01-18 Replacing crystal 3d model with step file that renders properly.
    [ABLS.STEP, omsdr.kicad_pcb]
2018-01-21 Added missing silk screen line
    [omsdr.kicad_pcb]
2018-01-21 Don't create gerber report
    [omsdr.kicad_pcb]
2018-02-13 Changed sample cap loading resistor frorm 10 Ohms to 49.9 Ohms
    [omsdr.sch]
2018-02-13 Component values for opamp feedback network
    [omsdr.sch]
2018-02-13 Multiplexer chip EOL, replaced with substitute order number
    [omsdr.sch]
2019-03-14 Updating PCB from schematic (no formal changes)
    [omsdr.kicad_pcb]
2019-03-15 Adding more component values and BOM digikey order numbers
    [omsdr.sch]
2019-03-15 Changes due to new kicad version (library upgrades etc.)
    [omsdr.sch]
2019-03-15 Bumping kicad-schlib to latest version of upstream
2019-03-15 Use FST3253 from kicad-schlib instead of cached
    [omsdr.sch]
2019-03-17 Replacing SMA connector since the one used was phased out from kicad
    No BOM as we are better off ordering this from China
    [omsdr.kicad_pcb, omsdr.sch]
2019-03-17 Changed my mind: Swapped SMA edge connector for smaller version
    [omsdr.kicad_pcb, omsdr.sch]
2019-03-17 Fixed silk screen of filter icon on back side of PCB
    [omsdr.kicad_pcb]
2019-03-17 Adding line to silk screen to indicate tiled edge of LT6231 package
    [omsdr.kicad_pcb]
2019-03-17 Reworked input bandpass filter
    [omsdr.kicad_pcb, omsdr.sch]
2019-03-17 Updated copyright dates
    [omsdr.kicad_pcb, omsdr.sch]
2019-03-17 Replaced footprints with versions from new kicad footprint library
    [omsdr.kicad_pcb, omsdr.sch]
2019-03-17 Adding pin header for IQ audio tap
    [omsdr.kicad_pcb, omsdr.sch]
2019-03-17 Replaced connector footprints with versions from new kicad footprint library
    [omsdr.kicad_pcb, omsdr.sch]
2019-03-17 Adding missing BOM fields
    [omsdr.sch]
2019-03-17 Bumping version to 1.2 on schematic and PCB
    [omsdr.kicad_pcb, omsdr.sch]
2019-05-20 New copyright owners for 1.2 version of the project.
    [omsdr.sch]
2019-05-20 Now official HB9UF project, add logo and rework silk.
    [omsdr.kicad_pcb]
2022-01-25 Bumping to KiCad version 6.0
    [omsdr.kicad_pcb, omsdr.kicad_sch, omsdr.sch]
2022-01-25 Adding year 2022 to copyright info
    [omsdr.kicad_pcb, omsdr.kicad_sch]
2022-01-25 Using attiny24 from the KiCad library (sch & pcb)
    [omsdr.kicad_pcb, omsdr.kicad_sch]
2022-01-25 Using LC6231 from the KiCad library (sch & pcb)
    [omsdr.kicad_pcb, omsdr.kicad_sch]
2022-01-25 Using headphone connector from the KiCad library (sch & pcb)
    [omsdr.kicad_pcb, omsdr.kicad_sch]
2022-01-25 Using Si5351 from the KiCad library (sch & pcb)
    [omsdr.kicad_pcb, omsdr.kicad_sch]
2022-01-25 Using FST3253 from the KiCad library (sch & pcb)
    [omsdr.kicad_pcb, omsdr.kicad_sch]
2022-01-25 Replacing some passives with current kicad symbols/footprints
    [omsdr.kicad_pcb, omsdr.kicad_sch]
2022-01-25 Removing old libraries and unneeded footprints
2022-01-25 Using M3 mouting holes from the KiCad library (sch & pcb)
    [omsdr.kicad_pcb, omsdr.kicad_sch]
2022-01-25 Removing kicad-pcblib submodule (dependency was removed)
2022-01-25 Registering 3D model of headphone jack
    [omsdr.kicad_pcb]
2022-01-25 Cleanup to satisfy DRC
    [omsdr.kicad_pcb]
2022-01-25 Removing stale 3D model for SMA connector
    [901-10003_REV-A.igs]
2022-01-25 Fixing BOM entry for SMA connector
    [omsdr.kicad_sch]
2022-01-25 Removing rescue and cache files since symbols are embedded in KiCad 6
2022-01-25 Setting solder mask clearance to 0
    Board house will use their own value and modify the gerbers.
    [omsdr.kicad_pcb]
2022-01-26 Using crystal footprint from the KiCad library (pcb & 3d model)
    [ABLS.STEP, omsdr.kicad_pcb, omsdr.kicad_sch]
2022-01-26 Replacing push buttons with current kicad footprints and 3d models
    [TL3342FxxxQG.stp, omsdr.kicad_pcb, omsdr.kicad_sch]
2022-01-27 Initial commit of firmware
    [omsdr.kicad_pcb]
2022-01-27 Reducing size of affiliation text on schematic
    [omsdr.kicad_sch]
2022-01-27 Adding schematics of rev 1.2 board (pdf and png)
2022-01-27 Removing csv files from .gitignore (useful for BOM)
2022-01-27 Adding BOM csv for rev 1.2
    [BOM_rev1.2.csv]
2022-01-27 Adding interactive BOM for rev 1.2.
